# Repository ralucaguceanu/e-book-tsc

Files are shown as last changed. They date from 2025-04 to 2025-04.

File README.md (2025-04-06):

## OpenBook-E-Book-Reader - _Guceanu Raluca-Zinca-Ioana - 331CD_

### Diagrama bloc a proiectului

tsc_diagrama

---

### BOM (Bill Of Materials) cu componentele 3D folosite

| Cantitate | Componentă | Mouser Link | Datasheet Link |
|-----|---|---|---|
| 30  | RC0402FR-07100KL | [link](https://ro.mouser.com/ProductDetail/YAGEO/RC0402FR-07100KL?qs=mnq%2FyloZIXzTlUn7JAHSWg%3D%3D) | [link](https://ro.mouser.com/datasheet/2/447/YAGEO_PYu_RC_Group_51_RoHS_L_12-3313492.pdf) |
| 26  | C0402C560J4HACAUTO | [link](https://ro.mouser.com/ProductDetail/KEMET/C0402C560J4HACAUTO?qs=j%252B1pi9TdxUae00jFMoJVSQ%3D%3D) | [link](https://ro.mouser.com/datasheet/2/447/KEM_C1007_X8R_ULTRA_150C_SMD-3316375.pdf) |
| 6 | PGB1010603MR | [link](https://ro.mouser.com/ProductDetail/Littelfuse/PGB1010603MR?qs=gu7KAQ731URLg4GSnNNN7Q%3D%3D) | [link](https://www.littelfuse.com/assetdocs/pulseguard-esd-suppressors-pgb1-datasheet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) |
| 3 | EVQPU-JA-02K | [link](https://ro.mouser.com/ProductDetail/Panasonic/EVQ-PUJ02K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) | [link](https://4donline.ihs.com/images/VipMasterIC/IC/PANA/PANA-S-A0003211477/PANA-S-A0004028532-1.pdf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) |
| 3 | MBR0530 | [link](https://ro.mouser.com/ProductDetail/onsemi/MBR0530T3G?qs=3JMERSakebpEmdUS6GetdQ%3D%3D) | [link](https://www.onsemi.com/PowerSolutions/product.do?id=MBR0530T3G) |
| 2 | SD0805S020S1R0 | [link](https://ro.mouser.com/ProductDetail/KYOCERA-AVX/SD0805S020S1R0?qs=jCA%252BPfw4LHbpkAoSnwrdjw%3D%3D) | [link](https://ro.mouser.com/datasheet/2/40/schottky-3165252.pdf) |
| 2 | Si1308EDL-T1-GE3 | [link](https://ro.mouser.com/ProductDetail/Vishay-Semiconductors/SI1308EDL-T1-GE3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) | [link](https://www.vishay.com/doc?63399) |
| 1 | USBLC6-2SC6Y | [link](https://ro.mouser.com/ProductDetail/STMicroelectronics/USBLC6-2SC6Y?qs=gNDSiZmRJS%2FOgDexvXkdow%3D%3D) | [link](https://ro.mouser.com/datasheet/2/389/usblc6_2sc6y-1852505.pdf) |
| 1 | BD5229G-TR | [link](https://ro.mouser.com/ProductDetail/ROHM-Semiconductor/BD5229G-TR?qs=4kLU8WoGk0vvnhrrYwdszw%3D%3D) | [link](https://fscdn.rohm.com/en/products/databook/datasheet/ic/power/voltage_detector/bd52xxg-e.pdf) |
| 1 | XC6220A331MR-G | [link](https://ro.mouser.com/ProductDetail/Torex-Semiconductor/XC6220A331MR-G?qs=AsjdqWjXhJ8ZSWznL1J0gg%3D%3D) | [link](https://ro.mouser.com/datasheet/2/760/xc6220-3371556.pdf) |
| 1 | FH34SRJ-24S-0.5SH_99_ | [link](https://ro.mouser.com/ProductDetail/Hirose-Connector/FH34SRJ-24S-0.5SH99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) | [link](https://ro.mouser.com/datasheet/2/185/FH34SRJ_24S_0_5SH_99__CL0580_1255_6_99_2DDrawing_0-1615044.pdf) |
| 1 | USB4110-GF-A | [link](https://ro.mouser.com/ProductDetail/GCT/USB4110-GF-A?qs=KUoIvG%2F9IlYiZvIXQjyJeA%3D%3D) | [link](https://ro.mouser.com/datasheet/2/837/GCT_USB4110_Product_Drawing___20k_cycles-3455479.pdf) |
| 1 | 112A-TAAR-R03_ATTEND | [link](https://www.digikey.ro/ro/products/detail/attend-technology/112A-TAAR-R03/17633923) | [link](https://www.attend.com.tw/data/download/file/112A-TAAR-R03_Spec.pdf) |
| 1 | TPC-4828 | [link](https://ro.mouser.com/ProductDetail/Wurth-Elektronik/744065151?qs=PGXP4M47uW53TYf%2FkIVaSQ%3D%3D) | [link](https://www.we-online.com/components/products/datasheet/744065151.pdf) |
| 1 | LG_R971-KN-1 | [link](https://ro.mouser.com/ProductDetail/ams-OSRAM/LG-R971-KN-1?qs=LsPilcdHE7EX1EB7GCLHxg%3D%3D) | [link](https://ro.mouser.com/datasheet/2/588/prd_pim_datasheet_2191277_EN_pdf-3419125.pdf) |
| 1 | MCP73831T-2ATI_OT | [link](https://ro.mouser.com/ProductDetail/Microchip-Technology/MCP73831T-2ATI-OT?qs=yUQqVecv4qsZbioEUu%252B83g%3D%3D) | [link](https://ro.mouser.com/datasheet/2/268/MCP73831_Family_Data_Sheet_DS20001984H-3441711.pdf) |
| 1 | PFMF.050.2 | [link](https://ro.mouser.com/ProductDetail/Schurter/PFMF.050.2?qs=1auRipcfynCums5v1iucSA%3D%3D) | [link](https://ro.mouser.com/datasheet/2/358/typ_PFMF-1275918.pdf) |
| 1 | DMG2305UX-7 | [link](https://ro.mouser.com/ProductDetail/Diodes-Incorporated/DMG2305UX-7?qs=L1DZKBg7t5F%2FNBHrjfxC%252Bg%3D%3D) | [link](https://www.diodes.com/assets/Datasheets/DMG2305UX.pdf) |
| 1 | BME688 | [link](https://ro.mouser.com/ProductDetail/Bosch-Sensortec/BME688?qs=IS%252B4QmGtzzqQoVDscqwx3A%3D%3D) | [link](https://ro.mouser.com/datasheet/2/783/bst_bme688_fl000-2307034.pdf) |
| 1 | CPH3225A | [link](https://ro.mouser.com/ProductDetail/Seiko-Semiconductors/CPH3225A?qs=3etwrb1wR%252BhUOph6lAO7eg%3D%3D) | [link](https://ro.mouser.com/datasheet/2/360/Seiko_Instruments_MicroBattery_E_20230330_2024Jan_-3561061.pdf) |
| 1 | W25Q512JVEIQ | [link](https://ro.mouser.com/ProductDetail/Winbond/W25Q512JVEIQ?qs=l7cgNqFNU1jw6svr3at6tA%3D%3D) | [link](https://ro.mouser.com/datasheet/2/949/Winbond_W25Q512JV_Datasheet-3240039.pdf) |
| 1 | ESP32-C6-WROOM-1-N8 | [link](https://ro.mouser.com/ProductDetail/Espressif-Systems/ESP32-C6-WROOM-1-N8?qs=8Wlm6%252BaMh8ST02Gmwp74cw%3D%3D) | [link](https://ro.mouser.com/datasheet/2/891/Espressif_ESP32_C6_WROOM_1__Datasheet_V0_1_PRELIMI-3239987.pdf) |
| 1 | DS3231SN# | [link](https://ro.mouser.com/ProductDetail/Analog-Devices-Maxim-Integrated/DS3231SN?qs=1eQvB6Dk1vhUlr8%2FOrV0Fw%3D%3D) | [link](https://ro.mouser.com/datasheet/2/609/DS3231-3421123.pdf) |
| 1 | MAX17048G+T10 | [link](https://ro.mouser.com/ProductDetail/Analog-Devices-Maxim-Integrated/MAX17048G%2bT10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) | [link](https://ro.mouser.com/datasheet/2/609/MAX17048_MAX17049-3469099.pdf) |
| 1 | Ada 4328 | [link](https://ro.mouser.com/ProductDetail/Adafruit/4328?qs=wnTfsH77Xs6Ypm3wH0xoXg%3D%3D) | [link](https://www.snapeda.com/parts/4328/Adafruit/view-part/?ref=mouser) |
| 1 | T491B226K006AT | [link](https://ro.mouser.com/ProductDetail/KEMET/T491B226K006AT?qs=jcsBHvPDQt8yMdJgz62biA%3D%3D) | [link](https://ro.mouser.com/datasheet/2/447/KEM_T2005_T491-3316937.pdf) |

---

### Descrierea Funcționalității Hardware a Ebook Reader-ului

Ebook readerul proiectat utilizează o arhitectură bazată pe microcontrolerul ESP32-C6, integrând multiple module pentru a oferi funcționalități avansate de afișare, stocare, conectivitate și monitorizare. Următoarea descriere detaliază componentele utilizate, interfețele de comunicare, specificațiile hardware și calculele de consum energetic.

---

### 1. Microcontroller Principal: ESP32-C6
- **Rol:** Controlul central al ebook readerului, procesare date și comunicație wireless.
- **Specificații:**
  - Interfețe: SPI, I2C, USB.
  - Alimentare: 3.3V.

**Interfațare cu module:**
- **E-Paper Display:** Interfață SPI pentru transfer rapid de date grafice.
- **Memorie NOR Flash:** SPI pentru stocare firmware și resurse grafice.
- **SD Card:** SPI pentru fișiere ebook.
- **RTC DS3231SN:** I2C pentru menținerea orei și alarme.
- **BME688 Sensor:** I2C pentru monitorizare mediu.
- **Baterie Li-Po:** I2C pentru monitorizarea prin Fuel Gauge (MAX17048).
- **USB-C:** Alimentare și transfer de date.
- **Qwiic/Stemma QT:** Conectarea rapidă a modulelor suplimentare.

---

### 2. Alimentare și Management Energie
- **Modul de Alimentare USB-C:** Asigură 5V pentru încărcare și comunicație USB 2.0.
- **LDO Voltage Regulator:** Convertor 5V -> 3.3V pentru alimentarea modulelor.
- **Protecție ESD:** TVS pe liniile USB pentru protecție la supratensiuni.
- **Baterie Li-Po:** Monitorizare prin MCP73831 și MAX17048 pentru încărcare și nivel de baterie.
- **Supercapacitor:** Menținerea energiei pe termen scurt.

**Calcul Consum:**
- Consum total estimat în funcționare: ~300 mA la 3.3V.
- În standby: ~50 mA datorită modului de consum redus al ESP32 și e-paper.

---

### 3. Module de Afișare
#### E-Paper Display
- **Control:** Prin interfața SPI (MOSI, MISO, SCK, CS).
- **Alimentare:** Tensiune 3.3V, controlată prin MOSFET pentru economisire.
- **Reset și Busy:** Monitorizate prin GPIO pentru sincronizare.

---

### 4. Stocare Externă
#### NOR Flash W25Q512JVEIQ (64MB)
- **Interfață:** SPI (CS, SCK, MISO, MOSI)
- **Rol:** Stocare firmware și resurse grafice.

#### SD Card
- **Interfață:** SPI pentru citire și scriere rapidă de date ebook.

---

### 5. Senzori și Monitorizare
#### Senzor BME688 (Temperatură, Umiditate, Presiune, Calitate Aer)
- **Interfață:** I2C.
- **Alimentare:** 3.3V.

#### Modulul RTC
- **Interfață:** I2C.
- **Alimentare Backup:** Supercapacitor pentru menținerea timpului în lipsa alimentării principale.
- **DS3231SN:** Menține timpul și data.

---

### 6. Interfața de Utilizator
- **Buton Reset:** Resetare manuală a microcontrollerului.
- **Buton Boot:** Intrare în modul programare.
- **Buton de Schimbare:** Configurabil pentru funcții speciale.

---

### 7. Testare și Monitorizare
- **Test Pads:** Puncte de test pentru măsurarea semnalelor SPI, UART, I2C și tensiuni critice.
- **Protecție ESD:** Pe toate liniile critice pentru prevenirea descărcărilor electrostatice.

---

### 8. Conectivitate Externă
#### Qwiic / Stemma QT
- **Interfață I2C:** Permite adăugarea rapidă de module senzoriale suplimentare.
- **Conectare Modulară:** Permite prototipare rapidă și flexibilă.

---

### Folosirea pinilor ESP32-C6

| Modul | Pini | Interfață | Motiv | 
| --- | --- | --- | --- |
| Modul RTC (DS3231) | IO0 - INT\_RTC, IO1 - 32KHz, IO18 - RST, IO21 - SDA, IO22 - SCL | I2C | Menține timpul chiar și atunci când ESP32 este oprit. |
| Card MicroSD | IO2 - MISO, IO4 - SS\_SD, IO6 - SCK, IO7 - MOSI | SPI | Permite stocarea și recuperarea fișierelor ebook. |
| Memorie Flash Externă (NOR) | IO2 - MISO, IO6 - SCK, IO7 - MOSI, IO11 - Flash CS | SPI | Oferă stocare suplimentară pentru datele aplicației. |
| E-Paper Display | IO3 - BUSY, IO5 - DC, IO6 - SCK, IO7 - MOSI, IO10 - EPD CS, IO23 - RST | SPI | Transferă datele de imagine către afișaj și controlează starea acestuia. |
| Senzor de Mediu (BME688) | IO21 - SDA, IO22 - SCL | I2C | Citește temperatura, umiditatea, presiunea și calitatea aerului. |
| Monitorizare Baterie | IO21 - SDA, IO22 - SCL | I2C | Citește tensiunea bateriei și starea de încărcare. |
| Diverse | IO9 - BOOT, IO15 - CHANGE, EN - RESET, NC - Not Connected | GPIO | Intrare de utilizator pentru interacțiunea cu dispozitivul. |

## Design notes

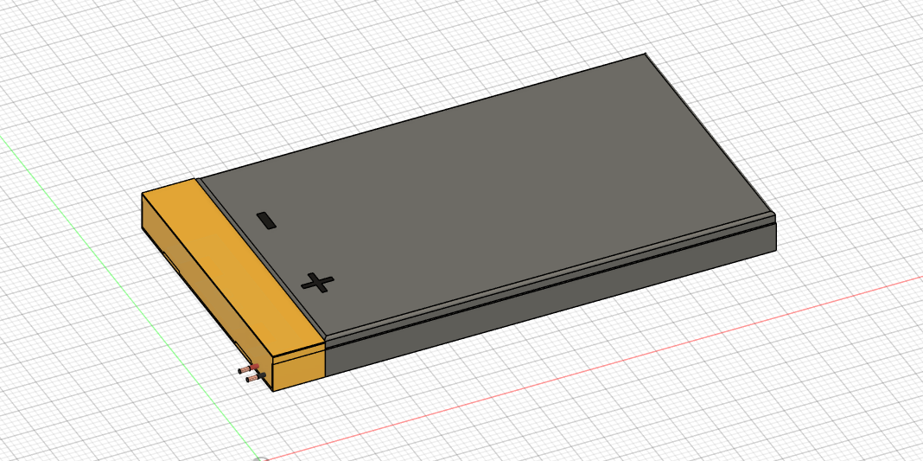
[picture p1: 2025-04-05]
Images/Battery.png

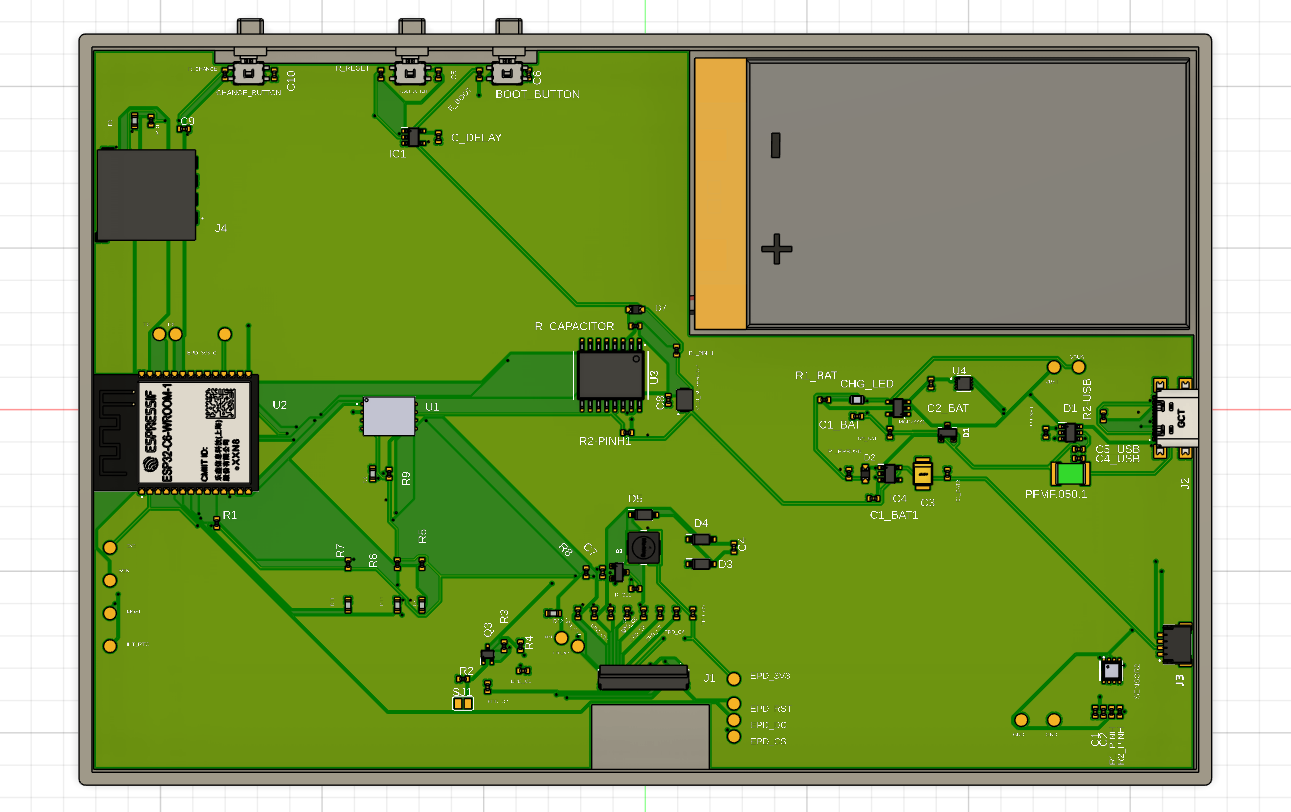
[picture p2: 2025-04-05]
Images/Board-with-Battery-and-Display-in-Box.png

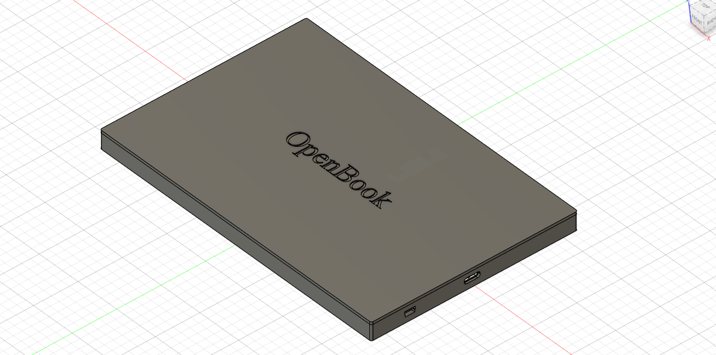
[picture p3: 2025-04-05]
Images/Full-Lateral-View-Bottom.png

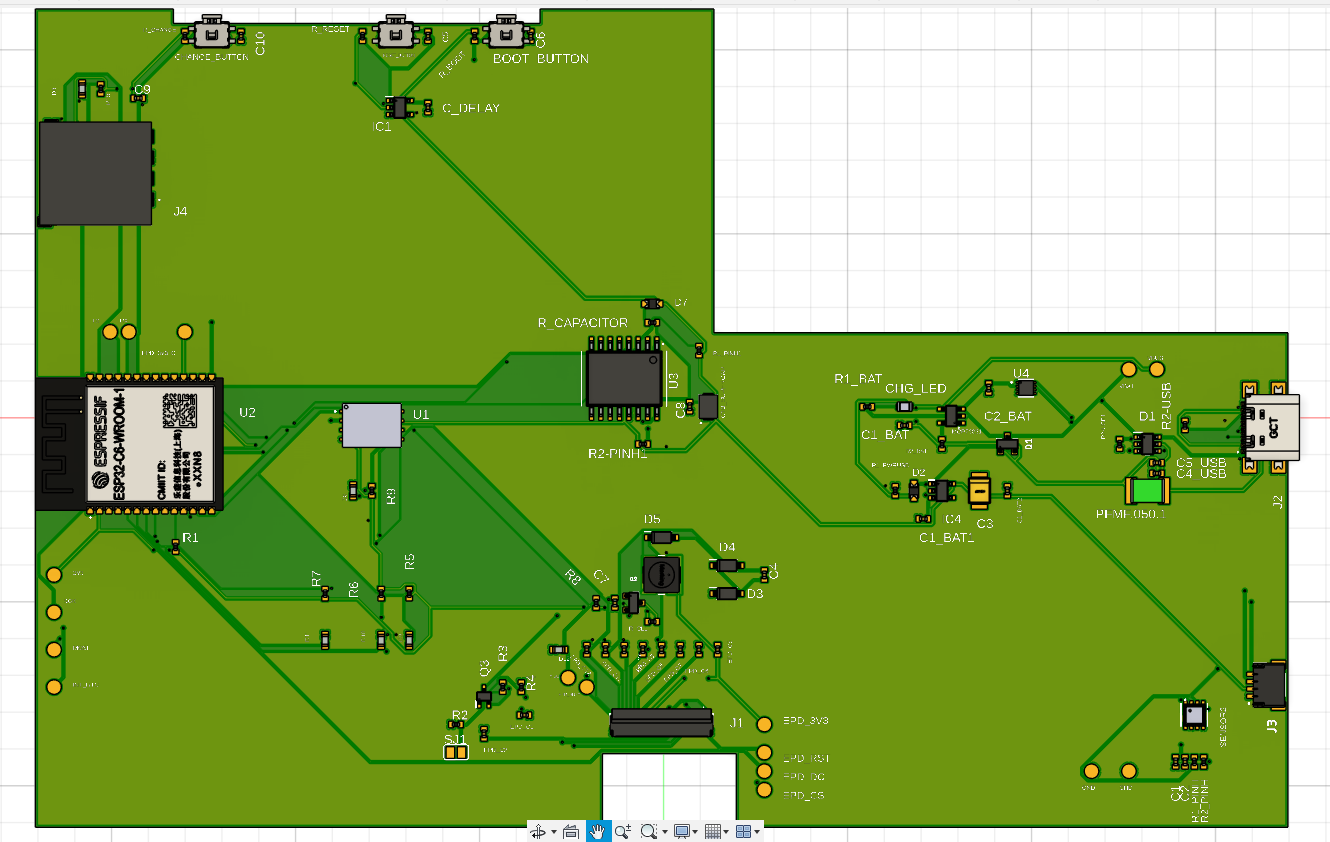
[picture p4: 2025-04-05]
Images/Board-TOP-View.png

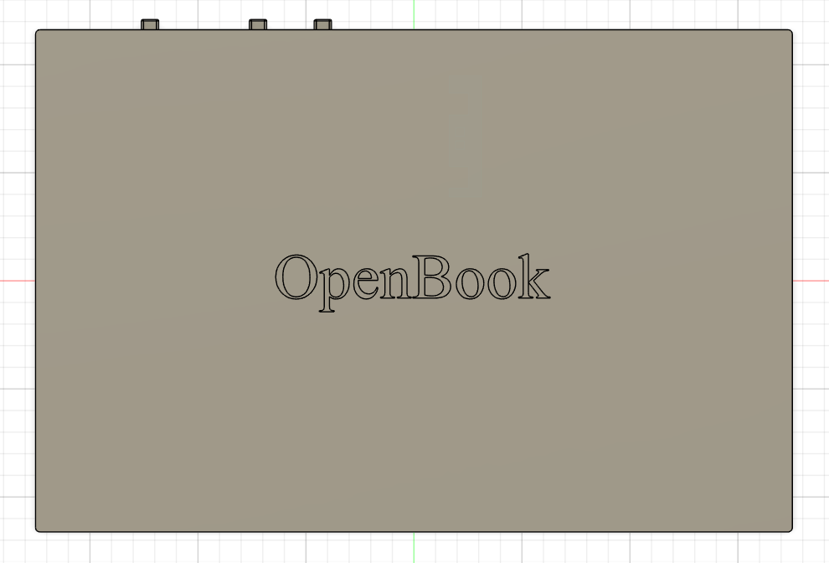
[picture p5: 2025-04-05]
Images/Lid-On.png

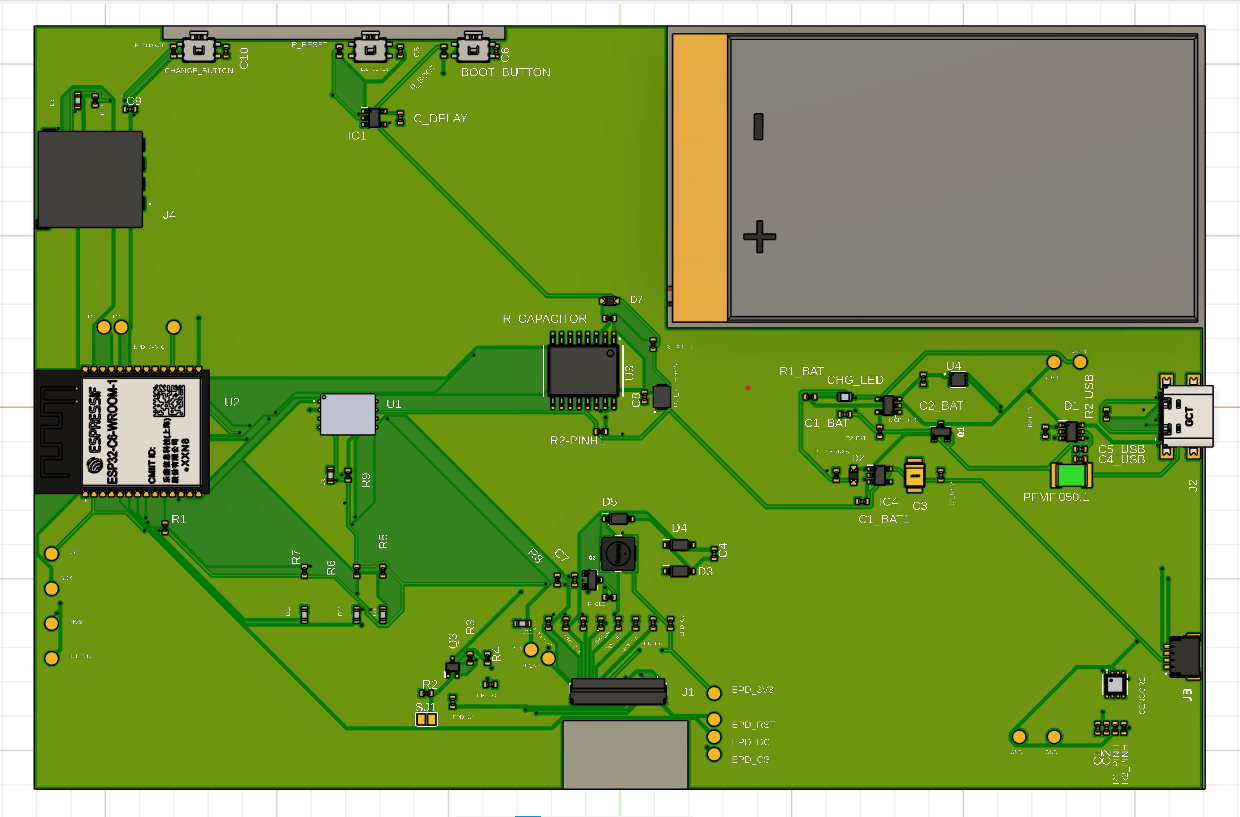
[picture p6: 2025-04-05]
Images/Board-with-Battery-and-Display.png

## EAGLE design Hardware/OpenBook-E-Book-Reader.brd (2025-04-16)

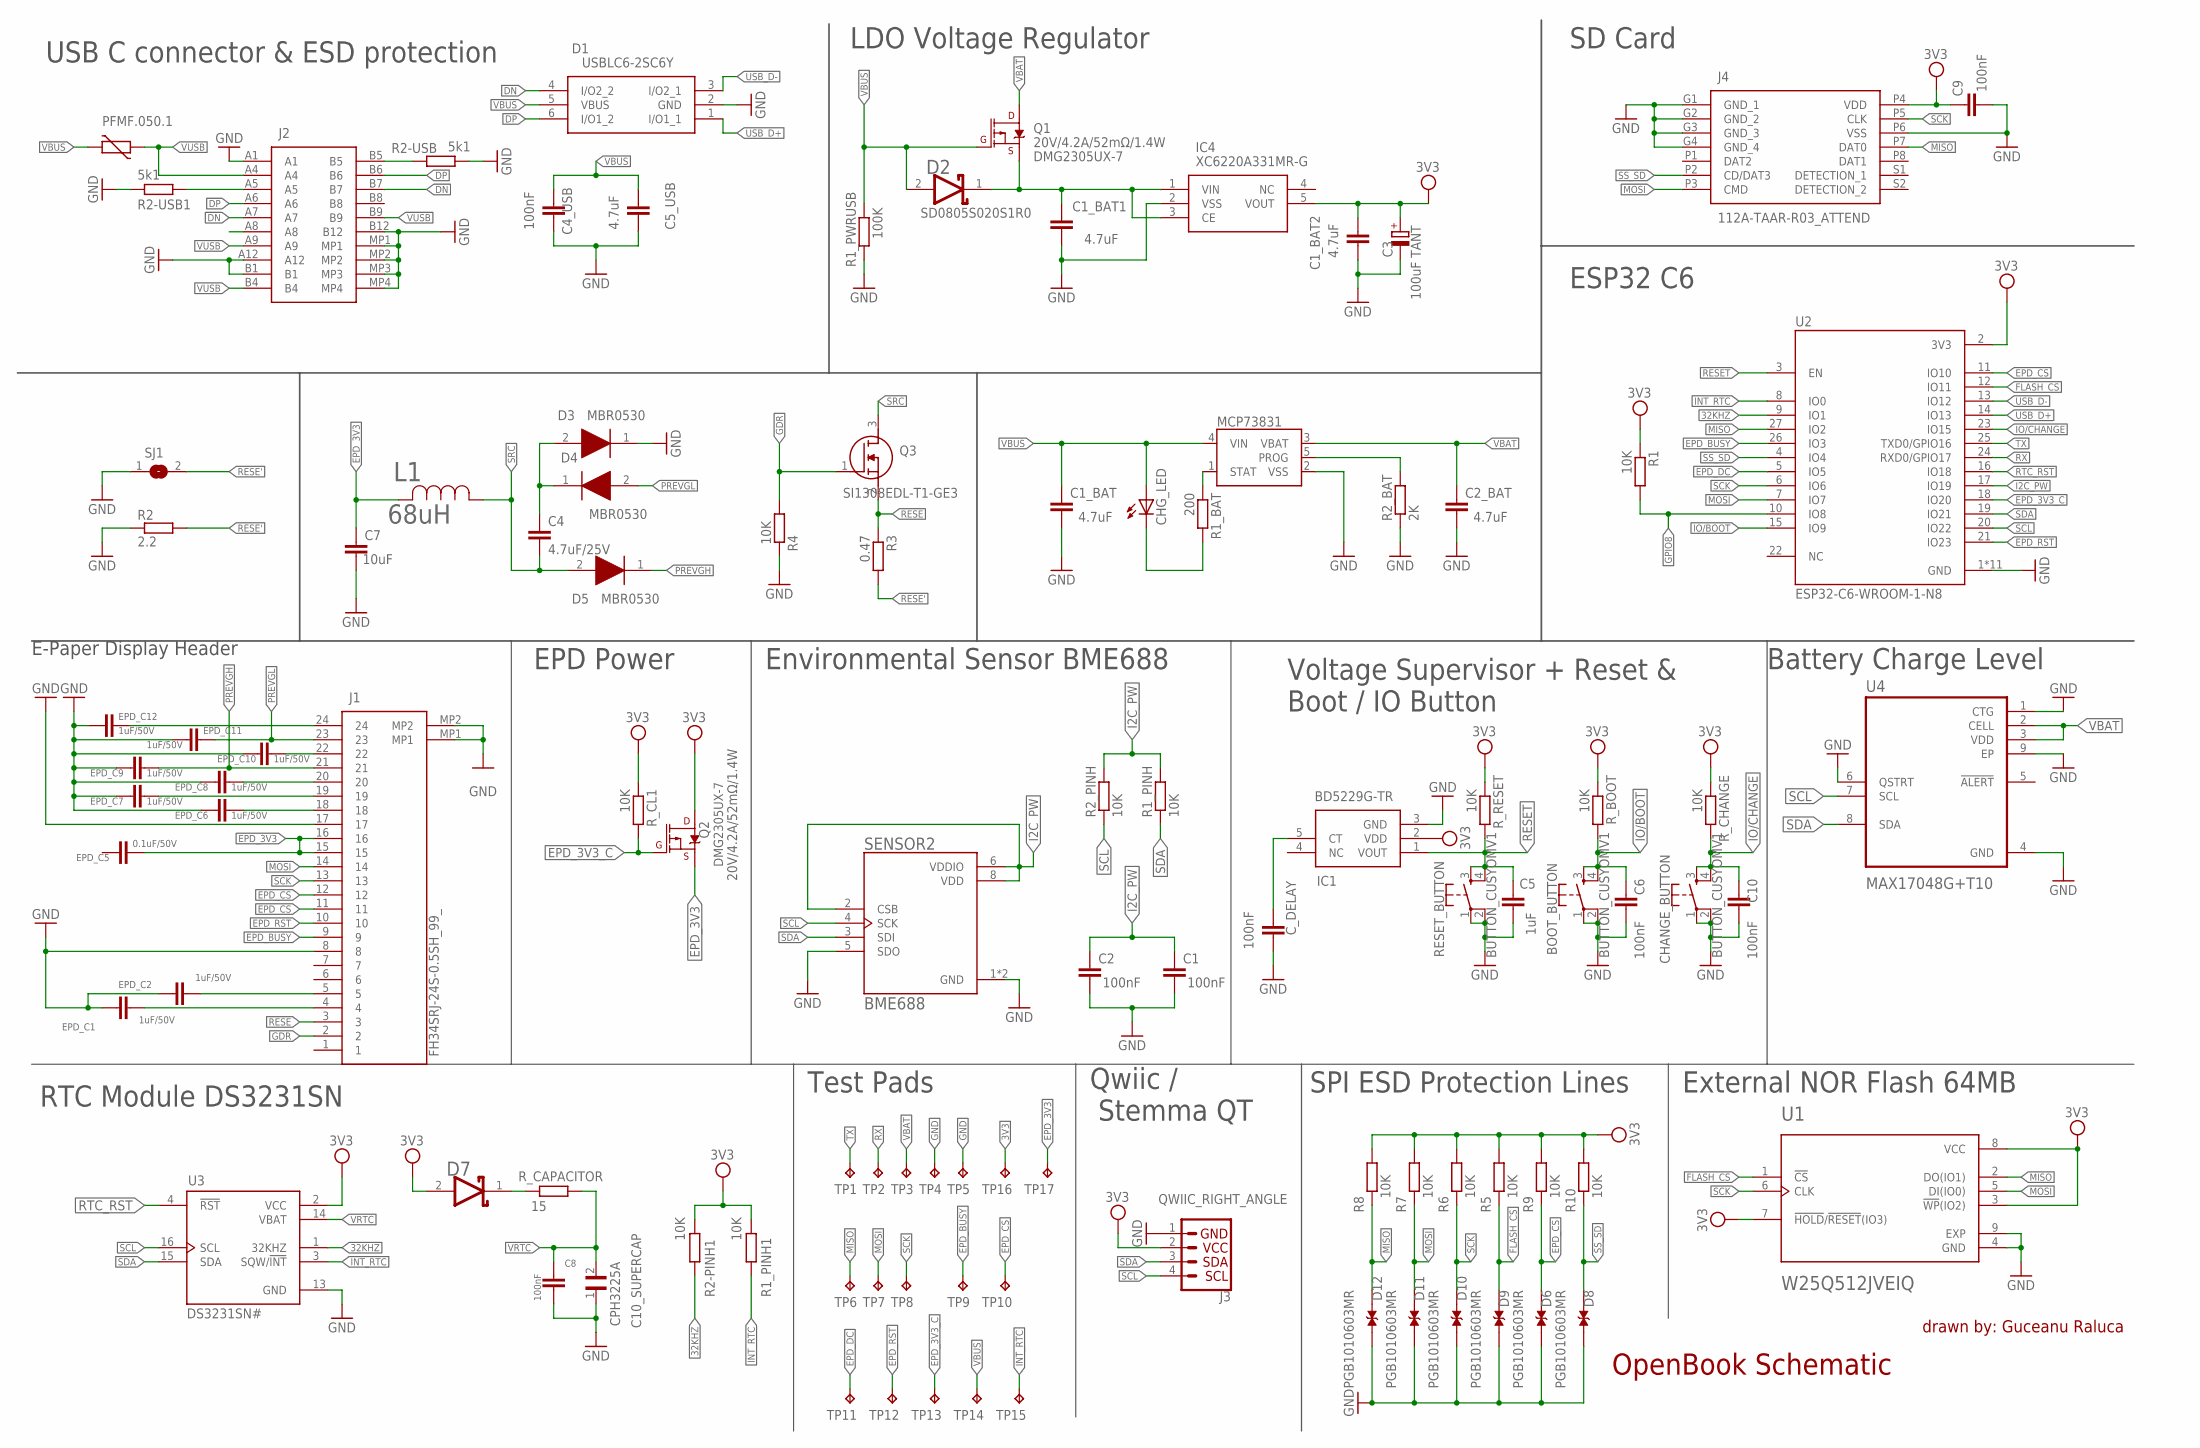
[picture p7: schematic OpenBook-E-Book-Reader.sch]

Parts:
BOOT_BUTTON: BUTTON_CUSYOMV1; MYBUTTON
C1, C2, C4_USB, C6, C8, C9, C10: 100nF; ESP32_WROVER_EAGLE-LTSPICE_C0402
C1_BAT, C1_BAT1, C1_BAT2, C2_BAT, C5_USB: 4.7uF; ESP32_WROVER_EAGLE-LTSPICE_C0402
C3: 100uF TANT; RCL_CT3528
C4: 4.7uF/25V; ESP32_WROVER_EAGLE-LTSPICE_C0402
C5: 1uF; ESP32_WROVER_EAGLE-LTSPICE_C0402
C7: 10uF; ESP32_WROVER_EAGLE-LTSPICE_C0402
C10_SUPERCAP: CPH3225A; CAPCP3225X100N
CHANGE_BUTTON: BUTTON_CUSYOMV1; MYBUTTON
CHG_LED: ADAFRUIT_LEDCHIP-LED0603; ADAFRUIT_CHIP-LED0603
C_DELAY: 100nF; ESP32_WROVER_EAGLE-LTSPICE_C0402
D1: USBLC6-2SC6Y; SOT95P280X145-6N
D2, D7: ESP32_WROVER_AVX---SD0805S020S1R0_AVX_SD0805S020S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; ESP32_WROVER_AVX---SD0805S020S1R0_AVX_SD0805S020S1R0_0
D3, D4, D5: MBR0530; SOD3716X135N
D6, D8, D9, D10, D11, D12: PGB1010603MR; DIOC1608X36N
EPD_C1, EPD_C2, EPD_C6, EPD_C7, EPD_C8, EPD_C9, EPD_C10, EPD_C11, EPD_C12: 1uF/50V; ESP32_WROVER_EAGLE-LTSPICE_C0402
EPD_C5: 0.1uF/50V; ESP32_WROVER_EAGLE-LTSPICE_C0402
IC1: BD5229G-TR; SOT95P280X125-5N
IC4: XC6220A331MR-G; SOT95P280X120-5N
J1: FH34SRJ-24S-0.5SH_99_; FH34SRJ24S05SH99
J2: SAMACSYS_PARTS_USB4110-GF-A; SAMACSYS_PARTS_USB4110GFA
J3: QWIIC_RIGHT_ANGLE; JST04_1MM_RA
J4: 112A-TAAR-R03_ATTEND; 112ATAARR03ATTEND
L1: 68uH; IND_4828-WE-TPC_WRE
MCP73831: ESP32_WROVER_SPARKFUN-IC-POWER_MCP73831; ESP32_WROVER_SPARKFUN-IC-POWER_SOT23-5
PFMF.050.1: ESP32C6_VARISTORCN1812; ESP32C6_VARISTOR_CT/CN1812
Q1, Q2: 20V/4.2A/52mΩ/1.4W; ESP32_WROVER_SPARKFUN-DISCRETESEMI_SOT23-3
Q3: SI1308EDL-T1-GE3; SOT65P210X110-3N
R1, R1_PINH, R1_PINH1, R2-PINH1, R2_PINH, R4, R5, R6, R7, R8, R9, R10: 10K; ESP32_WROVER_EAGLE-LTSPICE_R0402
R1_BAT: 200; ESP32_WROVER_EAGLE-LTSPICE_R0402
R1_PWRUSB: 100K; ESP32_WROVER_EAGLE-LTSPICE_R0402
R2: 2.2; ESP32_WROVER_EAGLE-LTSPICE_R0402
R2-USB, R2-USB1: 5k1; ESP32_WROVER_EAGLE-LTSPICE_R0402
R2_BAT: 2K; ESP32_WROVER_EAGLE-LTSPICE_R0402
R3: 0.47; ESP32_WROVER_EAGLE-LTSPICE_R0402
RESET_BUTTON: BUTTON_CUSYOMV1; MYBUTTON
R_BOOT: 10K; ESP32_WROVER_EAGLE-LTSPICE_R0402
R_CAPACITOR: 15; ESP32_WROVER_EAGLE-LTSPICE_R0402
R_CHANGE: 10K; ESP32_WROVER_EAGLE-LTSPICE_R0402
R_CL1: 10K; ESP32_WROVER_EAGLE-LTSPICE_R0402
R_RESET: 10K; ESP32_WROVER_EAGLE-LTSPICE_R0402
SENSOR2: BME688; ESP32_WROVER_BME680_PSON80P300X300X100-8N
SJ1: SJ
TP1, TP2, TP3, TP4, TP5, TP6, TP7, TP8, TP9, TP10, TP11, TP12, TP13, TP14, TP15, TP16, TP17: TPTP20R; TP20R
U1: W25Q512JVEIQ; SON127P600X800X80-9N
U2: ESP32-C6-WROOM-1-N8; XCVR_ESP32-C6-WROOM-1-N8
U3: DS3231SN#; SOIC127P1032X265-16N
U4: MAX17048G+T10; SON50P200X200X80-9N

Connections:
3V3: C1_BAT2.1, C3.+, C9.1, D7.2 (ANODE), IC1.2 (VDD), IC4.5 (VOUT), J3.2, J4.P4 (VDD), Q2.3 (D), R1.1, R1_PINH1.2, R2-PINH1.2, R5.1, R6.2, R7.2, R8.2, R9.2, R10.2, R_BOOT.1, R_CHANGE.1, R_CL1.1, R_RESET.1, TP16.TP, U1.3 (!WP!(IO2)), U1.7 (!HOLD!/!RESET!(IO3)), U1.8 (VCC), U2.2 (3V3), U3.2 (VCC)
32KHZ: R2-PINH1.1, U2.9 (IO1), U3.1 (32KHZ)
DN: D1.4 (I/O2_2), J2.A7, J2.B7
DP: D1.6 (I/O1_2), J2.A6, J2.B6
EPD_3V3: C7.1, EPD_C5.1, J1.15, J1.16, L1.2, Q2.2 (S), TP17.TP
EPD_3V3_C: Q2.1 (G), R_CL1.2, TP13.TP, U2.18 (IO20)
EPD_BUSY: J1.9, TP9.TP, U2.26 (IO3)
EPD_CS: D6.1, J1.11, J1.12, R9.1, TP10.TP, U2.11 (IO10)
EPD_DC: TP11.TP, U2.5 (IO5)
EPD_RST: J1.10, TP12.TP, U2.21 (IO23)
FLASH_CS: D9.1, R5.2, U1.1 (!CS), U2.12 (IO11)
GDR: J1.2, Q3.1 (G), R4.1
GND: BOOT_BUTTON.1, BOOT_BUTTON.2, C1.2, C1_BAT.2, C1_BAT1.2, C1_BAT2.2, C2.2, C2_BAT.2, C3.-, C4_USB.2, C5.2, C5_USB.2, C6.2, C7.2, C8.2, C9.2, C10.2, C10_SUPERCAP.1, CHANGE_BUTTON.1, CHANGE_BUTTON.2, C_DELAY.2, D1.2 (GND), D3.1 (K), D6.2, D8.2, D9.2, D10.2, D11.2, D12.2, EPD_C1.2, EPD_C2.2, EPD_C6.2, EPD_C7.2, EPD_C8.2, EPD_C9.2, EPD_C10.2, EPD_C11.2, EPD_C12.2, IC1.3 (GND), IC4.2 (VSS), J1.8, J1.17, J1.MP1, J1.MP2, J2.A1, J2.A12, J2.B1, J2.B12, J2.MP1, J2.MP2, J2.MP3, J2.MP4, J3.1, J4.G1 (GND_1), J4.G2 (GND_2), J4.G3 (GND_3), J4.G4 (GND_4), J4.P6 (VSS), MCP73831.2 (VSS), R1_PWRUSB.1, R2.1, R2-USB.2, R2-USB1.1, R2_BAT.1, R4.2, RESET_BUTTON.1, RESET_BUTTON.2, SENSOR2.1 (GND), SENSOR2.5 (SDO), SENSOR2.7 (GND), SJ1.1, TP4.TP, TP5.TP, U1.4 (GND), U1.9 (EXP), U2.1 (GND), U2.28 (GND), U2.29_1 (GND), U2.29_2 (GND), U2.29_3 (GND), U2.29_4 (GND), U2.29_5 (GND), U2.29_6 (GND), U2.29_7 (GND), U2.29_8 (GND), U2.29_9 (GND), U3.13 (GND), U4.1 (CTG), U4.4 (GND), U4.6 (QSTRT), U4.9 (EP)
GPIO8: R1.2, U2.10 (IO8)
I2C_PW: C1.1, C2.1, R1_PINH.2, R2_PINH.2, SENSOR2.2 (CSB), SENSOR2.6 (VDDIO), SENSOR2.8 (VDD), U2.17 (IO19)
INT_RTC: R1_PINH1.1, TP15.TP, U2.8 (IO0), U3.3 (SQW/!INT)
IO/BOOT: BOOT_BUTTON.3, BOOT_BUTTON.4, C6.1, R_BOOT.2, U2.15 (IO9)
IO/CHANGE: C10.1, CHANGE_BUTTON.3, CHANGE_BUTTON.4, R_CHANGE.2, U2.23 (IO15)
MISO: D12.1, J4.P7 (DAT0), R8.1, TP6.TP, U1.2 (DO(IO1)), U2.27 (IO2)
MOSI: D11.1, J1.14, J4.P3 (CMD), R7.1, TP7.TP, U1.5 (DI(IO0)), U2.7 (IO7)
unnamed: J2.B5, R2-USB.1
unnamed: C1_BAT1.1, D2.1 (CATHODE), IC4.1 (VIN), IC4.3 (CE), Q1.2 (S)
unnamed: C4.1, D3.2 (A), D4.1 (K)
unnamed: J2.A5, R2-USB1.2
unnamed: D7.1 (CATHODE), R_CAPACITOR.2
unnamed: CHG_LED.C, R1_BAT.2
unnamed: MCP73831.5 (PROG), R2_BAT.2
unnamed: MCP73831.1 (STAT), R1_BAT.1
unnamed: EPD_C12.1, J1.24
unnamed: C_DELAY.1, IC1.5 (CT)
unnamed: EPD_C10.1, J1.22
unnamed: EPD_C8.1, J1.20
unnamed: EPD_C7.1, J1.19
unnamed: EPD_C6.1, J1.18
unnamed: EPD_C2.1, J1.5
unnamed: EPD_C1.1, J1.4
PREVGH: D5.1 (K), EPD_C9.1, J1.21
PREVGL: D4.2 (A), EPD_C11.1, J1.23
RESE: J1.3, Q3.2 (S), R3.1
RESE': R2.2, R3.2, SJ1.2
RESET: C5.1, IC1.1 (VOUT), RESET_BUTTON.3, RESET_BUTTON.4, R_RESET.2, U2.3 (EN)
RTC_RST: U2.16 (IO18), U3.4 (!RST)
RX: TP2.TP, U2.24 (RXD0/GPIO17)
SCK: D10.1, J1.13, J4.P5 (CLK), R6.1, TP8.TP, U1.6 (CLK), U2.6 (IO6)
SCL: J3.4, R2_PINH.1, SENSOR2.4 (SCK), U2.20 (IO22), U3.16 (SCL), U4.7 (SCL)
SDA: J3.3, R1_PINH.1, SENSOR2.3 (SDI), U2.19 (IO21), U3.15 (SDA), U4.8 (SDA)
SRC: C4.2, D5.2 (A), L1.1, Q3.3 (D)
SS_SD: D8.1, J4.P2 (CD/DAT3), R10.1, U2.4 (IO4)
TX: TP1.TP, U2.25 (TXD0/GPIO16)
USB_D+: D1.1 (I/O1_1), U2.14 (IO13)
USB_D-: D1.3 (I/O2_1), U2.13 (IO12)
VBAT: C2_BAT.1, MCP73831.3 (VBAT), Q1.3 (D), TP3.TP, U4.2 (CELL), U4.3 (VDD)
VBUS: C1_BAT.1, C4_USB.1, C5_USB.1, CHG_LED.A, D1.5 (VBUS), D2.2 (ANODE), MCP73831.4 (VIN), PFMF.050.1.2, Q1.1 (G), R1_PWRUSB.2, TP14.TP
VRTC: C8.1, C10_SUPERCAP.2, R_CAPACITOR.1, U3.14 (VBAT)
VUSB: J2.A4, J2.A9, J2.B4, J2.B9, PFMF.050.1.1

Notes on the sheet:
USB C connector & ESD protection
LDO Voltage Regulator
SD Card
ESP32 C6
E-Paper Display Header
RTC Module DS3231SN
Test Pads
Qwiic / Stemma QT
SPI ESD Protection Lines
External NOR Flash 64MB
Battery Charge Level
Voltage Supervisor + Reset & Boot / IO Button
Environmental Sensor BME688
EPD Power
OpenBook Schematic
drawn by: Guceanu Raluca

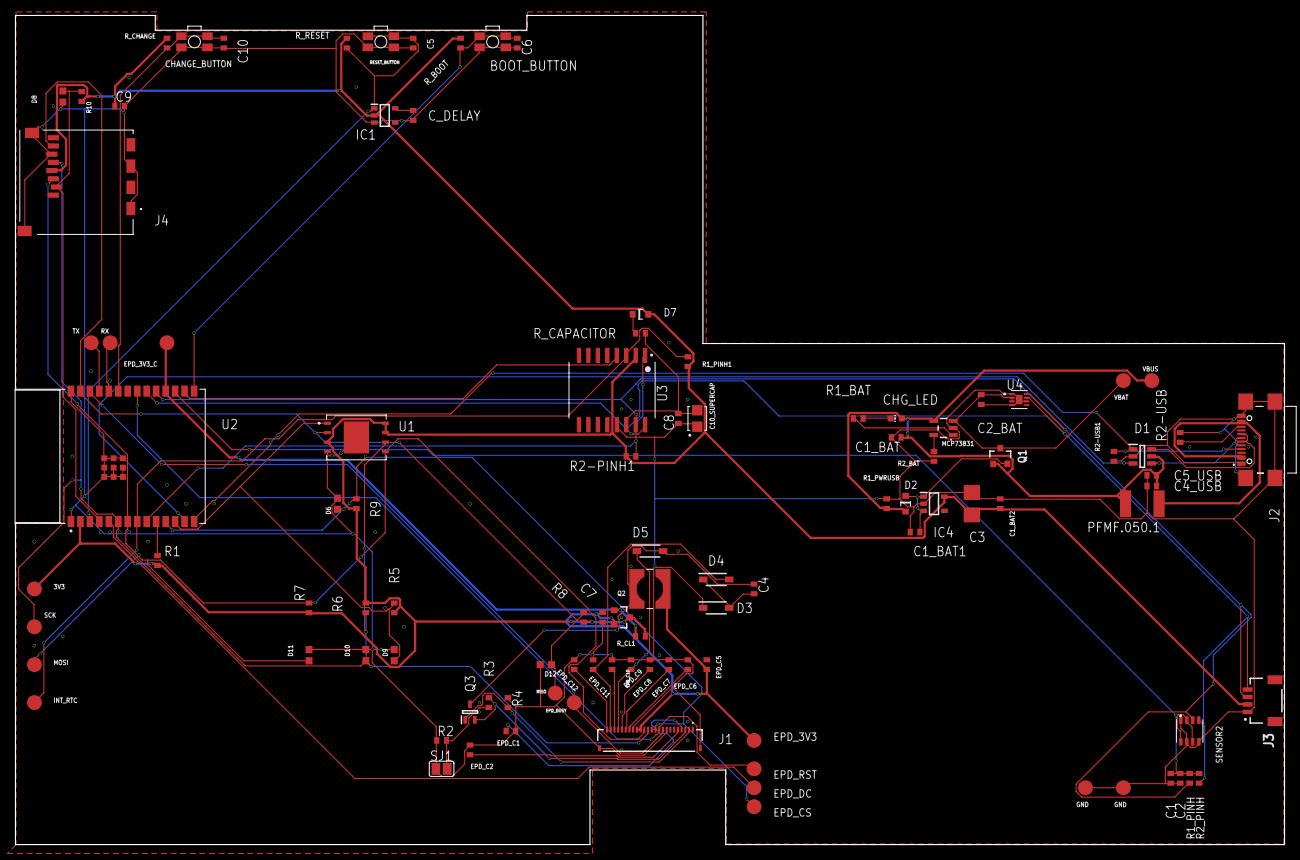
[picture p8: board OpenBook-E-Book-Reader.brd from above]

Board: 2 copper layers, 170.2 x 111.2 mm, 103 parts (0 on the bottom side), 55 nets.

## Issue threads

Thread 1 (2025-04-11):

Grosime PCB

mihaelazaluceanu, 2025-04-11:
### Grosime PCB
Pentru o potrivire cât mai adevăratâ cu carcasa dispozitivului, board ul forțează necesitatea unei grosimi de 1mm.
În proiect, grosimea a rămas cea default.

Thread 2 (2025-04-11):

Planul de masă

mihaelazaluceanu, 2025-04-11:
### Planul de masă
Se prezintă cu spații neacoperite. Pentru a asigura trecerea de pe partea de front pe partea de back a placuței fără a crea goluri => adăugare de via stiching.

Closed 2025-04-16.

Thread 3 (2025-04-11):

Exploded View

mihaelazaluceanu, 2025-04-11:
### Exploded View
În momentul deschiderii fișierului, dispozitivul pare asamblat; componentele nu sunt separate una de alta pentru o vizualizare în detaliu a acestora.

Closed 2025-04-16.

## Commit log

2025-04-05 add hardware and manufacturing files
    [OpenBook-E-Book-Reader.brd, OpenBook-E-Book-Reader.sch]
2025-04-06 upload Bill-of-Materials.csv
    [Bill-of-Materials.csv]
2025-04-06 upload Pick-and-Place.csv
    [Pick-and-Place.csv]
2025-04-06 upload Bill-of-Materials.bom and Pick-and-Place.cpl files
2025-04-16 update OpenBook-E-Book-Reader.brd
    refacerea planului de masa
    [OpenBook-E-Book-Reader.brd]
2025-04-16 update OpenBook-E-Book-Reader.f3z
    rezolvare grosime 3D PCB

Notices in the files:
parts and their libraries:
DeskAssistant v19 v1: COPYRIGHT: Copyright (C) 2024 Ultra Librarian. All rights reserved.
